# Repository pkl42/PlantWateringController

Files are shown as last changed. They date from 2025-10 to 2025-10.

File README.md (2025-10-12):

# PlantWateringController

An open-source IoT system for **automated plant watering and monitoring**, built around an **ESP32 controller**, **Tasmota ESP8266 sensors**, and a **Node-RED dashboard** with **InfluxDB** time-series storage.

---

## Features
- ESP32-based **Plant Controller** for moisture-driven watering control  
- ESP8266 Wi-Fi sensors (Tasmota) with **deep sleep** and MQTT telemetry  
- **Node-RED Dashboard 2.0** for live visualization and manual override  
- **InfluxDB 2.0** for time-series logging and analytics  
- Modular 3D-printed housings (Fusion 360) for pumps, sensors, and enclosures  
- Supports both **wired** and **wireless** capacitive moisture sensors

---

## System Overview

[ ESP8266 Sensor ] ─── MQTT ───┐
│
[ Node-RED ] ─── [ InfluxDB ]
│
[ ESP32 Controller ] <─────────┘

---

## Quick Start

### 1️⃣ Flash the ESP32 Controller
- Code in: `/firmware/esp32_controller`
- Built using **PlatformIO**
- Configure Wi-Fi and MQTT broker in `config.h`

### 2️⃣ Configure ESP8266 Sensor
- Flash **Tasmota**
- Apply rules from `/firmware/esp8266_sensor_tasmota/tasmota_rules.md`
- Set up **telemetry** every few minutes
- Example payload: `tele/plantSensor/STATE`

### 3️⃣ Import Node-RED Flow
- Import `/nodered/flows.json`
- Set MQTT and InfluxDB connection nodes
- Adjust dashboard layout if needed

### 4️⃣ InfluxDB Setup
- Create a bucket, retention policy, and token
- See `/influxdb/retention_policy_setup.md`

### 5️⃣ Optional Hardware Setup
- Print 3D housings from `/cad/`
- See `/docs/build_guide.md` and `/docs/wiring.md`

---

## Repository Structure
| Folder | Description |
|---|---|
| `firmware/` | ESP32 controller firmware + Tasmota sensor setup |
| `nodered/` | Dashboard flow and UI elements |
| `cad/` | Fusion 360 source, STL exports, and renders |
| `hardware/` | Wiring diagrams and bill of materials |
| `influxdb/` | Database configuration and example queries |
| `docs/` | Guides, build notes, and overviews |

---

## Recommended Tools
- [PlatformIO](https://platformio.org/)
- [Node-RED Dashboard 2.0](https://flows.nodered.org/)
- [InfluxDB 2.x](https://www.influxdata.com/)
- [Fusion 360](https://www.autodesk.com/products/fusion-360/)
- [Fritzing](https://fritzing.org/) (optional for wiring diagrams)

---

## License
This project is open-source.  
You can use or modify it under the **Apache 2.0 License** (see [LICENSE](LICENSE)).

---

## Author
Created by **Peter Ludwig**  
Designed for modular smart plant care and automation.

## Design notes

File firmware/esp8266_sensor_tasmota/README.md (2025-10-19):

# ESP8266 Tasmota Moisture Sensor Firmware

This folder contains the setup and configuration guide for using an ESP8266-based soil moisture sensor running **Tasmota** firmware within the Plant Watering Controller system.

## Overview

This setup turns a low-cost ESP8266 board (e.g. Wemos D1 Mini) into a self-contained soil moisture sensor.  
It reads the analog input (A0), publishes the value via MQTT, and can enter **deep sleep** to save power.

---

## Installation Guide

### 1. Download and Flash Tasmota

**Note 1:** For flashing the wiring between D0 and RST needs to be interupted.  
**Note 2:** Your browser does need to support Web Serial, use Google Chrome or Microsoft Edge.

1. Go to [https://tasmota.github.io/install/](https://tasmota.github.io/install/).
2. Connect your ESP8266 board via USB.
3. Select **Tasmota Sensors** from your browser.
4. Configure your Wi-Fi Access right now and click on "Visit Device"-Option.
or  
5. Connect to the Wi-Fi access point created by the ESP8266 (SSID `tasmota-XXXX`).
6. Enter your Wi-Fi credentials and reconnect to your network.

**Note 3:** After flashing the wiring between D0 and RST needs to be reconnected.  

Additional Information: [https://tasmota.github.io/docs/Getting-Started/#initial-configuration](https://tasmota.github.io/docs/Getting-Started/#initial-configuration)

---

### 2. Initial Setup

1. Access the Tasmota web interface (just the ip-address of the connected device, e.g. <http://192.168.0.186>).  
   You can get it e.g. from your router in the list of connected devices.  
   If you configured the Wi-Fi Access right during flashing process you can directly click on the  
   "Visit Device"-Option.
2. Go to **Configuration → Module → Module Type: Generic (18)**. Then click on Save to restart the device.
3. Go to **Configuration → Module and now set the Module Parameters like on the screenshot.

#### Template & Pin Configuration

| Setting | Description |
|---|---|
| Module Type | Generic (18) |
| A0 | Analog sensor input |
| Power1 | GPIO used to power the sensor (optional) |
| Others | Leave unconfigured |

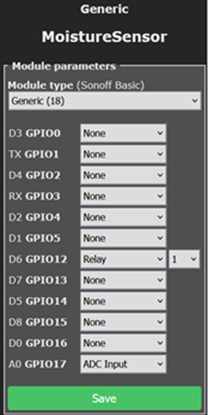
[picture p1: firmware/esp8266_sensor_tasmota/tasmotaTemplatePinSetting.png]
Generic Template Setting
  

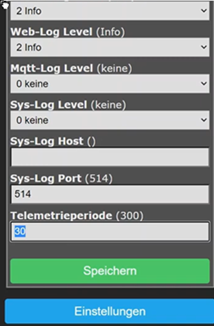
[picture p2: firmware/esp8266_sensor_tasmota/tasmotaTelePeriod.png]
TelePeriod Configuration
  

---

### 3. Configure MQTT

Set your MQTT broker connection in **Configuration → Configure MQTT**:

| Setting | Example |
|---|---|
| Host | `192.168.1.105` |
| Port | `1883` |
| Topic | `MS_%06X` |

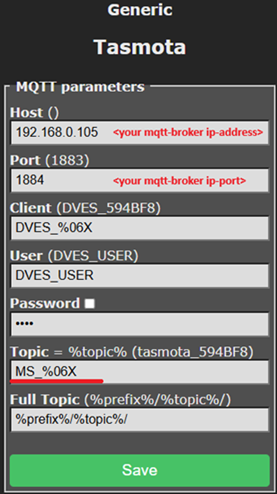
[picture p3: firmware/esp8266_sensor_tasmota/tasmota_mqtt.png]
MQTT Configuration


---

### 4. Load the Rules

Paste the rules from [`tasmota_rules.md`](./tasmota_rules.md) into the **Tasmota Console**, then enable them:

Enable rules:

~~~bash
Rule1 1

ruletimer1 3
~~~

The rule handle ADC reading, MQTT publishing, and optionally entering deep sleep mode.  
The <device_topic> is also used in the plant controller in Nodered, and as it should not be modified,  
mark the device with this <device_topic>.

---

### 5. MQTT Communication

The sensor periodically publishes its moisture readings via MQTT.  
You can manually set the deep sleep interval by publishing to:

~~~bash
cmnd/MS_594908/Mem3 0
~~~

| Value | Meaning |
|---|---|
| `0` | Stay awake (no sleep) |
| `>0` | Deep sleep time in seconds |

Example telemetric message: [`tele_format_example.json`](./tele_format_example.json)

~~~json
{
  "Time": "2025-10-06T15:29:58",
  "utctime": 1759760998,
  "adc": 268
}
~~~

---

Some mqtt commands i used during testing

~~~bash
mosquitto_pub -h 192.168.0.105 -t cmnd/MS_594908/mem3 -m <x>    # 0 No DeepSleep >0 DeepSleep in seconds

-r retained
-n delete retained message
mosquitto_pub -h 192.168.0.105 -t cmnd/MS_594908/mem3 -r -n 
~~~

---

## See Also

- [Node-RED integration](../../nodered/README.md)
- [InfluxDB example queries](../../influxdb/example_queries.md)
- [Hardware notes](../../hardware/README.md)

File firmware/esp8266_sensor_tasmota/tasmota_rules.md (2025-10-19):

# Tasmota Rules for Moisture Sensor

This rule control the ESP8266 moisture sensor behavior, MQTT reporting, and deep sleep cycle.  
The power for the sensor is controlled by output pin

---

## Rule1

~~~text
Rule1
ON System#Boot DO Backlog Power1 1; TelePeriod 30; Var3 2; DeepSleepTime 0 ENDON
  
ON Mqtt#Connected DO RuleTimer1 3 ENDON

ON Mem1#state= do backlog if ($Mem1 == "") Mem1 752 endon
ON Mem2#state= do backlog if ($Mem2 == "") Mem2 283 endon

ON Analog#A0 DO 
 Var1 %value%
 ENDON
 
ON Rules#Timer=1 DO 
 Backlog
 publish2 tele/%topic%/MOISTURE {"Time":"%timestamp%","utctime":%utctime%,"adc":%Var1%};
 Var3 = %Var3%-1;

 IF ((%Mem3%>0) && (%Var3%<1)) Backlog Publish stat/%topic%/debug Going_to_sleep; DeepSleepTime %Mem3% ENDIF;
 IF (%Mem3%==0 || %Var3%>0) Backlog Publish stat/%topic%/debug Restart_Timer1; RuleTimer1 10; DeepSleepTime %Mem3% ENDIF;

ENDON
~~~

**Explanation**

| Variable | Description |
| --- | --- |
| `Var1` | Stores latest ADC (moisture) value |
| `Var3` | Countdown until deep sleep |
| `Mem1`, `Mem2` | Optional calibration memory values, currently decomissioned  |
| `Mem3` | DeepSleepTime in seconds (set via MQTT) |
| `TelePeriod` | Telemetry interval |
| `Power1` | Turns sensor supply pin ON |
| `RuleTimer1` | Timer controlling when moisture data is sent |

**MQTT Command to Set Sleep Time**

cmnd/<device_topic>/Mem3 <seconds>

~~~text
cmnd/MS_594908/Mem3 600
~~~

→ Sleeps for 10 minutes after sending next telemetry packet.  
When device returns from Deepsleep, the DeepSleepTime is set to 0. Otherwise there would be no chance  
to switch off the deep sleep mode by mqtt message. Vice versa to fall in deep sleep again the
cmnd/<device_topic>/Mem3-topic should be retained message.

Debug Output (Example)

~~~text
stat/<device_topic>/debug Restart_Timer1
stat/<device_topic>/debug Going_to_sleep

stat/MS_594908/debug Restart_Timer1
stat/MS_594908/debug Going_to_sleep
~~~

These messages are useful for monitoring device behavior in Node-RED or the MQTT broker.

---

### **firmware/esp8266_sensor_tasmota/tele_format_example.json**

~~~json
{
  "Time": "2025-10-06T15:29:58",
  "utctime": 1759760998,
  "adc": 268
}
~~~

### Experiences and Issues

During developing the rule i tried to do the conversion into percentage value within the rule,  
but for some reason the calculated value delayed significant from raw value.

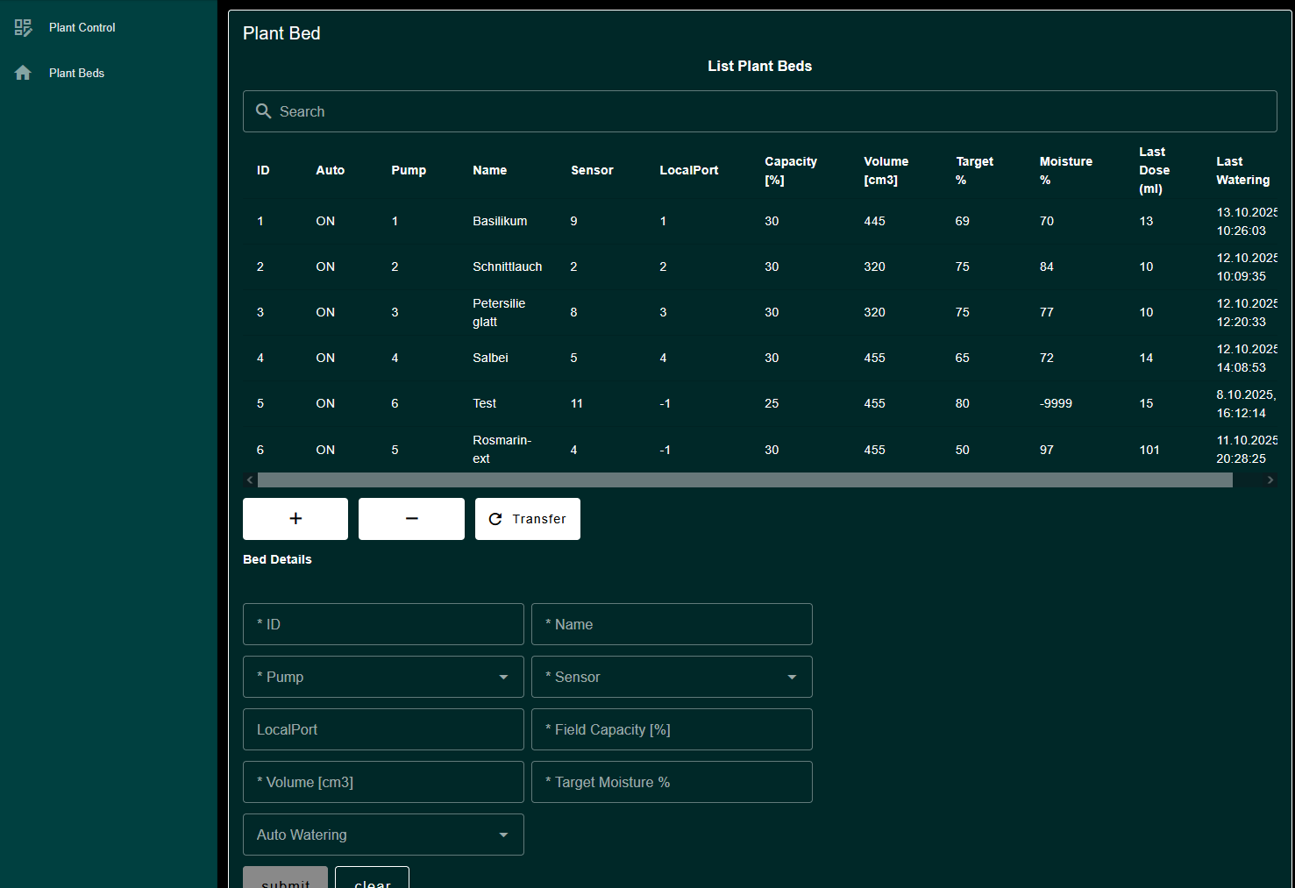
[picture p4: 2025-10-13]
nodered/dashboard_screenshots/PlantBeds.png

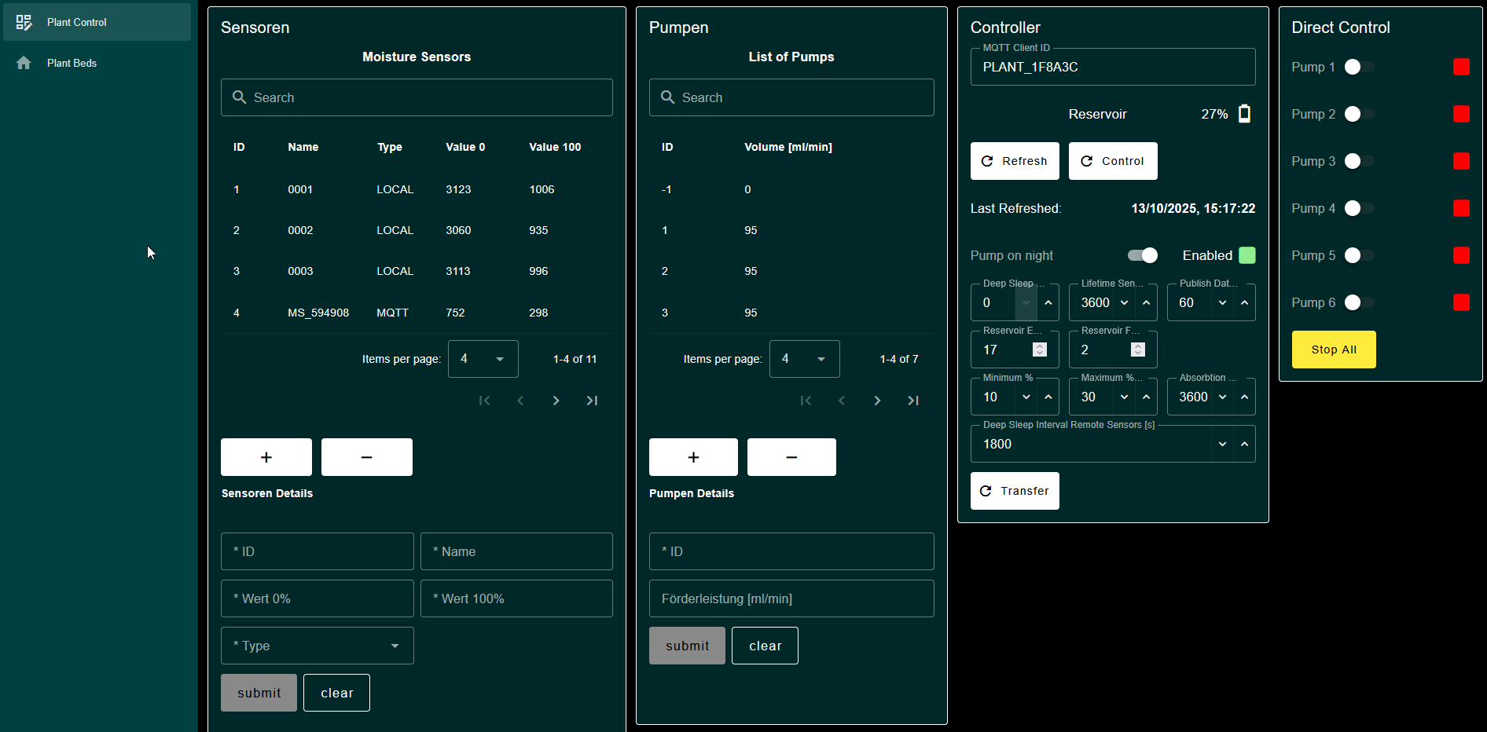
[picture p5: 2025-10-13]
nodered/dashboard_screenshots/PlantControl.png

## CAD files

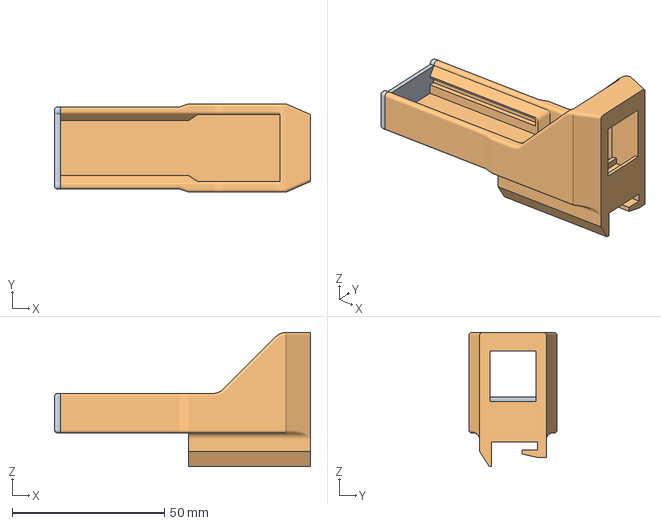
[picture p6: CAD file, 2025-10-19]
cad/clamps_tubes/SensorDistributorBox_V2.3mf
84.0 x 29.0 x 44.0 mm
Körper1 x 2

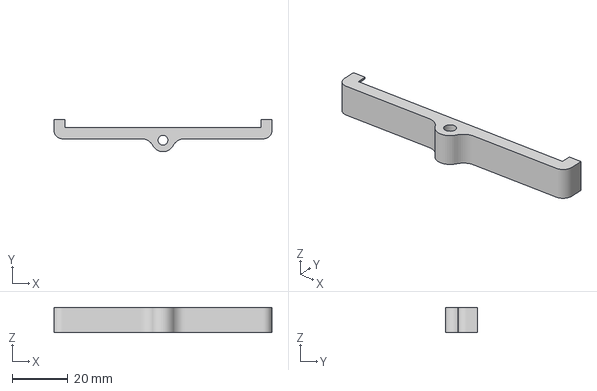
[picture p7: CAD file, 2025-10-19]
cad/main_box/MOSFET BoardHolder.3mf
78.0 x 11.6 x 9.00 mm

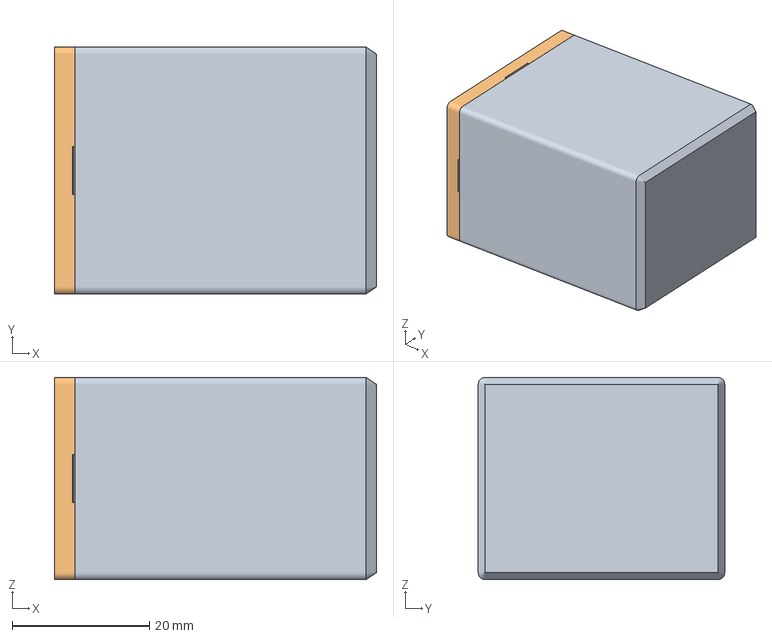
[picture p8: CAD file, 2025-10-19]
cad/sensor_unit/SensorHousing_450mAh_V1.8.3mf
47.0 x 36.0 x 29.5 mm
SensorHousing_450mAh
SensorHousing_450mAh_Base

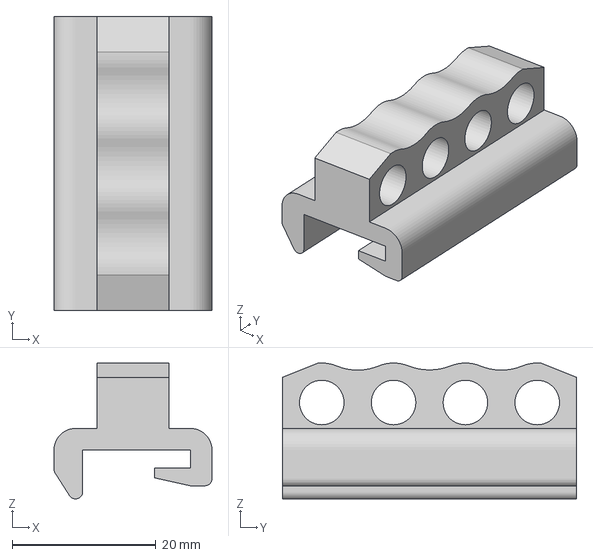
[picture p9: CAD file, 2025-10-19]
cad/clamps_tubes/ClampAdapter_Tubes_V2.3mf
22.0 x 41.0 x 18.9 mm

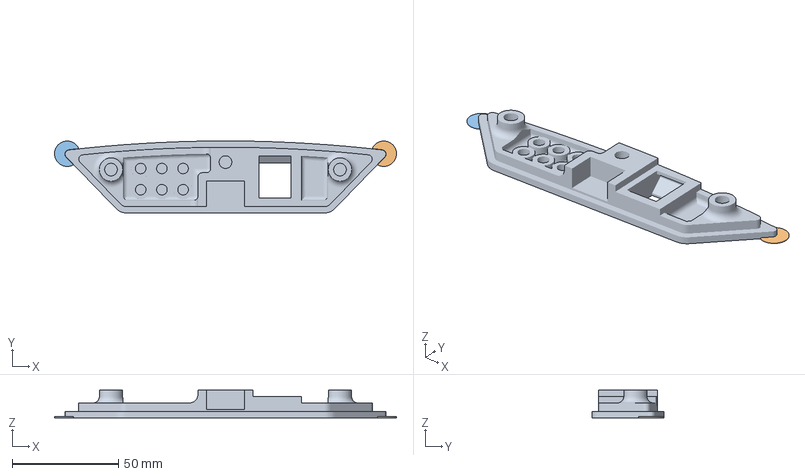
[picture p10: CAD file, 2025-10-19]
cad/main_box/GrabHandleAdapter_RJ45.3mf
161.3 x 34.0 x 13.0 mm
Körper1
Körper2
Körper3

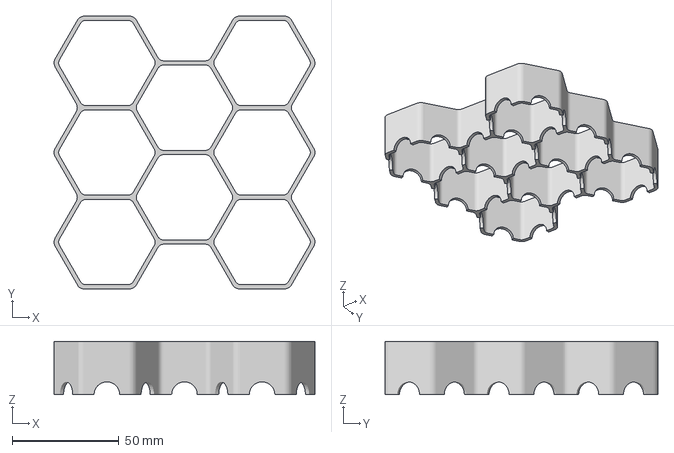
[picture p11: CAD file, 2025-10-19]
cad/miscellaneous/PlantSaucer.3mf
122.3 x 128.0 x 25.0 mm

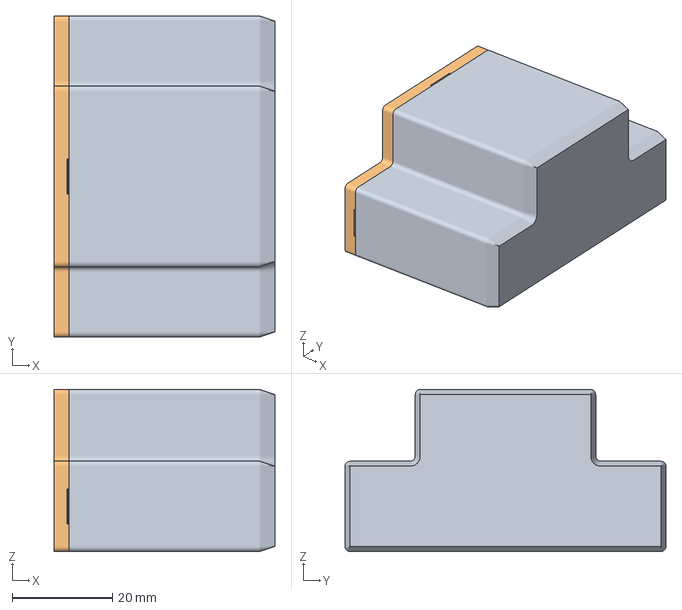
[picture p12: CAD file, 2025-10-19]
cad/sensor_unit/SensorHousing_2000mAh_V2.6.3mf
44.0 x 64.0 x 32.3 mm
SensorHousing_2000mAh
SensorHousing_2000mAh_Base

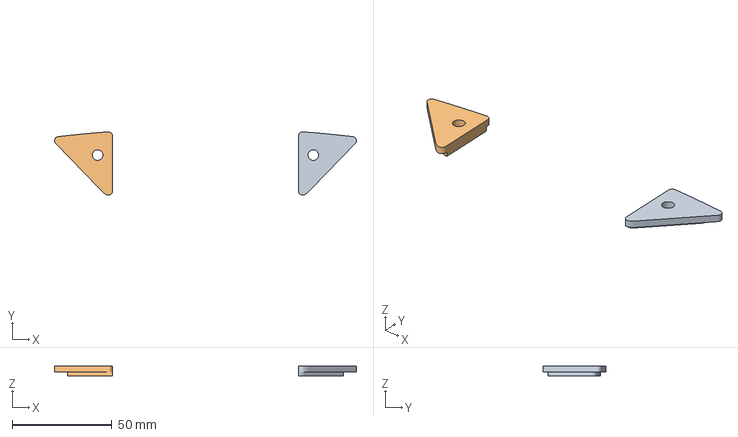
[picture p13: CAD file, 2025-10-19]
cad/main_box/Counterparts.3mf
151.3 x 31.7 x 5.00 mm
Körper1 x 2

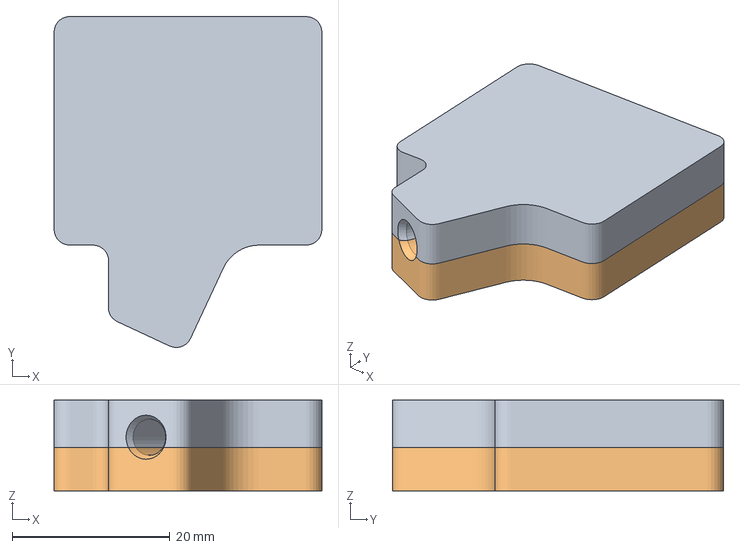
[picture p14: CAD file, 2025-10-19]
cad/sensor_unit/SensorHousingDirect.3mf
34.0 x 42.0 x 11.5 mm
SensorHousingNative1
SensorHousingNative2

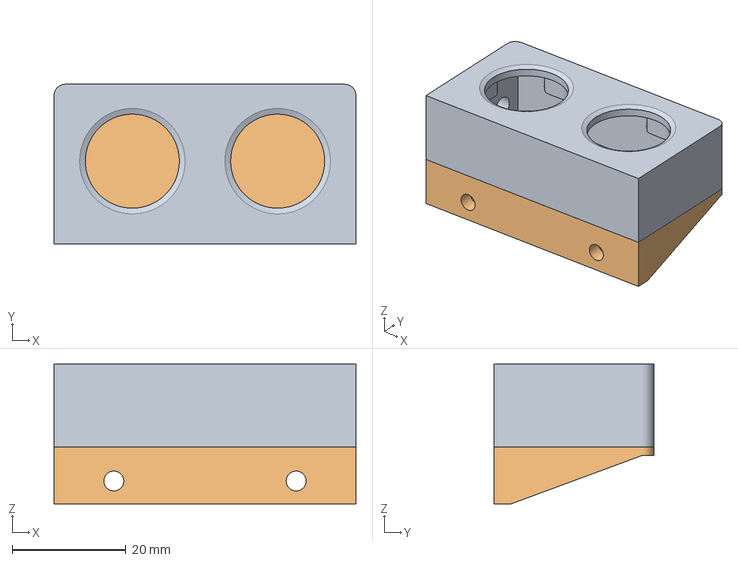
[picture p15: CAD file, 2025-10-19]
cad/main_box/UltrasonicSensor_HC-SR04 _V2.3mf
53.0 x 28.0 x 24.5 mm
Körper1 x 2

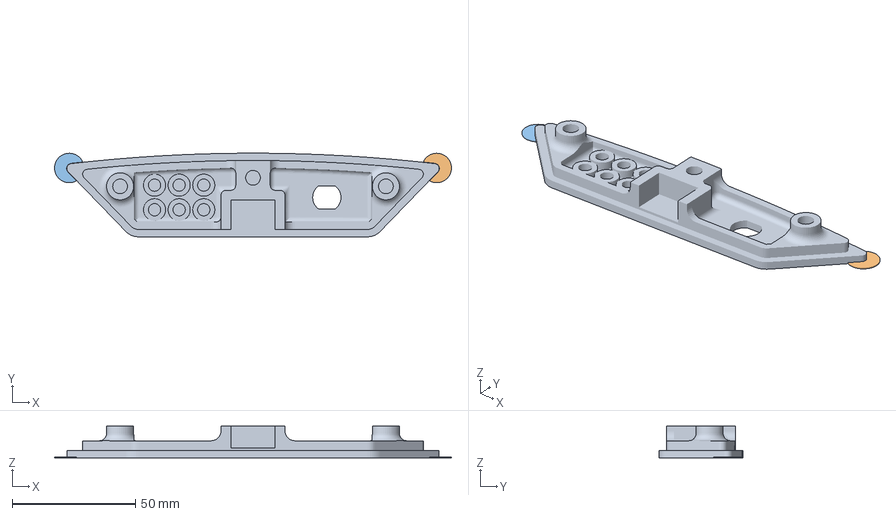
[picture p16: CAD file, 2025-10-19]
cad/main_box/GrabHandleAdapter_USB.3mf
161.3 x 34.0 x 13.0 mm
Körper1
Körper2
Körper3

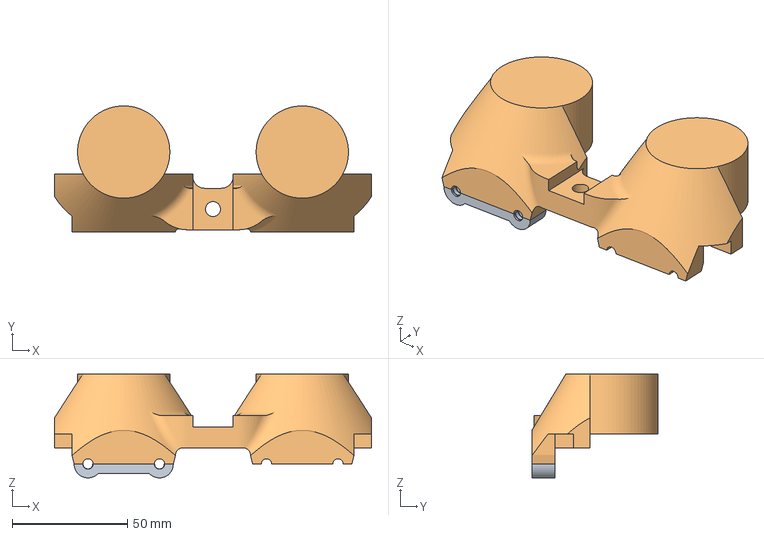
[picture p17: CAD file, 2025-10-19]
cad/main_box/PumpHolder_V4.3mf
137.4 x 54.7 x 45.0 mm
Körper2 x 2

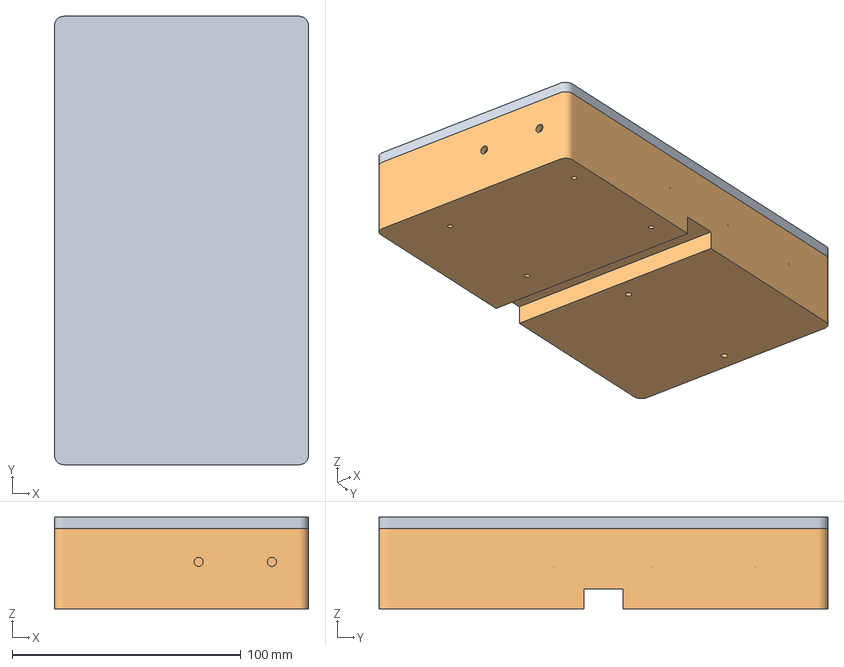
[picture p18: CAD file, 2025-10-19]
cad/main_box/ControlCabinet_V1.3mf
111.0 x 196.0 x 40.0 mm
Körper1 x 2

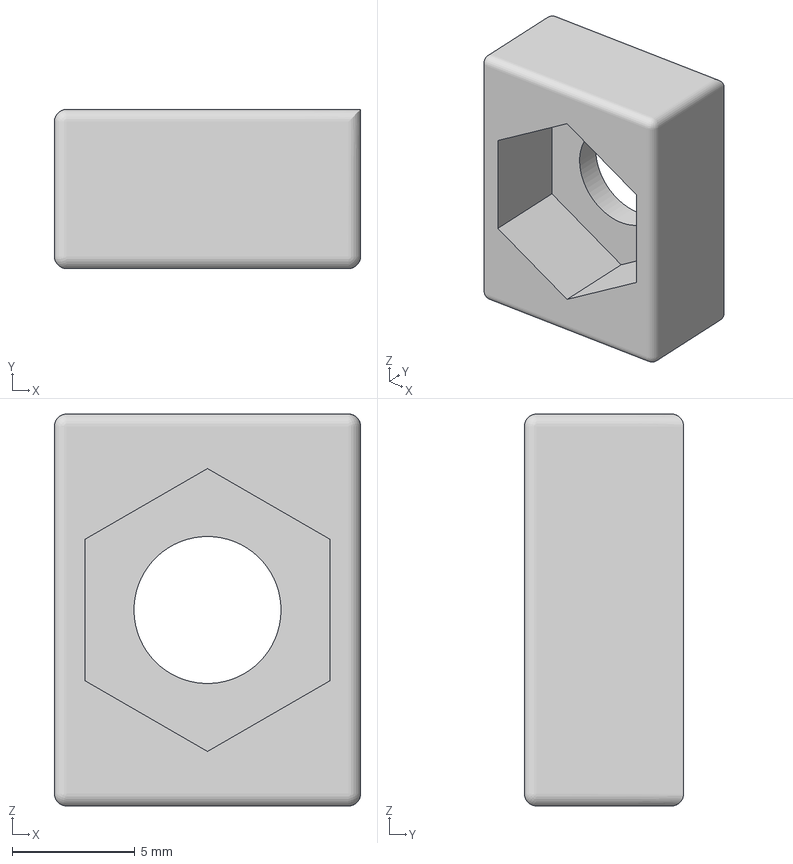
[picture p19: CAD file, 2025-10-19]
cad/miscellaneous/T-Nut_M6_Nut.3mf
12.5 x 6.50 x 16.0 mm

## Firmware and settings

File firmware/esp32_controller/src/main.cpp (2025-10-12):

/*
 * SPDX-FileCopyrightText: 2025 Peter Ludwig
 *
 * SPDX-License-Identifier: Apache-2.0
 */

#include "PlantController.h"
#include <configFile.h>
#include <DualWifiMode.h>
#include "WebServerBase.h"
#include "OTAHandler.h"

JsonDocument config_doc;
MyAppConfig config("/config.cfg");
WebConfigServer configServer(80);

TimeZone tz("pool.ntp.org", "CET-1CEST,M3.5.0,M10.5.0/3");
PlantController controller(tz);

// Manual IP Configuration for Soft AP
IPAddress AP_LOCAL_IP(192, 168, 5, 10);
IPAddress AP_GATEWAY_IP(192, 168, 5, 254);
// Url for access: http://192.168.5.10/
// Define Pin to indicate start option
const uint8_t AP_PIN = 23; // do not use GPIO11!!!-crashes

void setup()
{
  WiFiModeStatus wifi_status;
  Serial.begin(115200);
  delay(200);
  Serial.println("=== ESP32 Plant Watering Controller ===");

  // config.remove();
  config_doc = config.read_config();

  initDualWiFiConfig(AP_PIN,
                     config_doc["ap_ssid"],
                     config_doc["ap_password"],
                     config_doc["ln_ssid"],
                     config_doc["ln_password"],
                     AP_LOCAL_IP,
                     AP_GATEWAY_IP);

  wifi_status = startDualWiFi();

  if (wifi_status == WiFiModeStatus::AP)
  {
    configServer.setDefaults(config_doc);
    configServer.onConfigSaved([&](const JsonDocument &doc)
                               { config.write_config(&doc); });
    Serial.println("start");
    configServer.start();
  }

  // Init OTA (you can also pass hostname and password if desired)
  setupOTA("esp32-ota", nullptr);

  // Init Plant Controller

  controller.init(config_doc["mqtt_broker_ip"],
                  static_cast<uint16_t>(config_doc["mqtt_broker_port"].as<int>()));
}

void loop()
{
  if (!otaInProgress)
  { // only run normal tasks if OTA is not happening
    // In deep sleep mode, run() will sleep at the end
    // In continuous mode, run() will return immediately and be called again
    if (controller.connectToMQTTBroker())
    {
      controller.subscribeCmndTopics();
      controller.run();
    }
  }

  handleOTA(); // must be called regularly
}

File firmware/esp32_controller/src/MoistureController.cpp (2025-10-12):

/*
 * SPDX-FileCopyrightText: 2025 Peter Ludwig
 *
 * SPDX-License-Identifier: Apache-2.0
 */

#include "MoistureController.h"
#include <ArduinoJson.h>

#include "esp_log.h"

IMoistureSensor::IMoistureSensor(TimeZone &timeZone, const String &sensorName)
    : tz(timeZone), sensorName(sensorName)
{
}

void IMoistureSensor::setCalibration(int dry, int wet)
{
    if (dry != VALUE_NOT_SET)
    {
        rawDry = dry;
    }
    if (wet != VALUE_NOT_SET)
    {
        rawWet = wet;
    }
}

void IMoistureSensor::setRaw(int rawValue, unsigned long utcTime)
{
    lastReadRaw = rawValue;

    if (utcTime > 0)
    {
        // Use provided UTC/Epoch timestamp
        lastUpdateRaw = utcTime;
        lastUpdateRawUsingEpoch = true;
        // ESP_LOGI("", "setRaw utcTime %lu, %lu, %i, %i", utcTime, lastUpdateRaw, lastReadRaw, lastUpdateRawUsingEpoch);
    }
    else
    {
        // Fallback to system time or millis
        lastUpdateRaw = tz.getNow(lastUpdateRawUsingEpoch);
        // ESP_LOGI("", "setRaw Fallback %lu, %i, %i", lastUpdateRaw, lastReadRaw, lastUpdateRawUsingEpoch);
    }
}

void IMoistureSensor::setPercent(float percentValue, unsigned long utcTime)
{
    lastReadPer = percentValue;

    if (utcTime > 0)
    {
        // Use provided UTC timestamp
        lastUpdatePer = (unsigned long)utcTime * 1000UL;
        lastUpdatePerUsingEpoch = true;
    }
    else
    {
        // Fallback to system time or millis
        lastUpdatePer = tz.getNow(lastUpdatePerUsingEpoch);
    }
    // ESP_LOGI("", "setPercent %u, %i", lastUpdateRaw, lastReadRaw);
}

bool IMoistureSensor::isDataValid(unsigned long lastUpdate, bool dateInUtc)
{
    unsigned long nowMs = tz.getNow(lastCheckUtc);
    return (nowMs - lastUpdate) <= maxLifetimeMs;
}

void IMoistureSensor::setLifetime(unsigned int lifetimeSec)
{
    maxLifetimeMs = lifetimeSec * 1000UL;
    ESP_LOGI(sensorName, "Lifetime updated to %u seconds", lifetimeSec);
}

unsigned int IMoistureSensor::getLifeTime()
{
    return (unsigned int)(maxLifetimeMs / 1000UL);
}

//
// private functions
//

//
// MoistureSensorLocal
//
MoistureSensorLocal::MoistureSensorLocal(TimeZone &timeZone, const String &sensorName, int pin, int dry, int wet)
    : IMoistureSensor(timeZone, sensorName)
{
    IMoistureSensor::connType = ConnectionType::LOCAL;
    sensorPin = pin;
    setCalibration(dry, wet);
}

void MoistureSensorLocal::init()
{
    if (sensorPin > 0)
    {
        analogSetPinAttenuation(sensorPin, ADC_11db);
        analogReadResolution(12);
        // Enable internal pull-up to bias floating pin
        pinMode(sensorPin, INPUT_PULLUP);
        analogRead(sensorPin); // warm-up read
    }
}

void MoistureSensorLocal::setPin(int pin)
{
    if (pin == sensorPin)
    {
        return;
    }

    sensorPin = pin;
    init();
}

MoistureData MoistureSensorLocal::readPercent()
{
    MoistureData result{};
    result.percent = INVALID_FLOAT;
    result.timestamp = 0;

    int raw = readRaw();
    if (raw == INVALID_INT)
    {
        return result;
    }
    result.timestamp = getRawTimestamp();

    if (rawWet == rawDry)
    {
        result.percent = 100.0f; // fail-safe: assume fully wet
        return result;
    }

    float pct = ((float)(rawDry - raw) * 100.0f) / (float)(rawDry - rawWet);
    pct = constrain(pct, 0.0f, 100.0f);

    result.percent = pct;

    return result;
}

int MoistureSensorLocal::readRaw()
{
    const int samples = 8;
    long acc = 0;
    for (int i = 0; i < samples; i++)
    {
        acc += analogRead(sensorPin);
        delay(2);
    }
    lastReadRaw = (acc / samples);
    // --- Detect invalid reading ---
    // Your "dry" baseline is around 3100–3200.
    // Floating w/ pull-up will be closer to 4095 (max at 12-bit).
    int helpInt = lastReadRaw;
    if ((lastReadRaw > 3500) || (lastReadRaw < 800))
    {
        // Mark as invalid (you can choose 0, -1, or a special flag)
        lastReadRaw = INVALID_INT;
    }
    // ESP_LOGI("", "%s lastReadRaw %i => %i", (this->getSensorName()).c_str(), helpInt, lastReadRaw);
    setRaw(lastReadRaw);
    return lastReadRaw;
}

//
// ----- MoistureSensorMQTT Class -----
//

const char *TOPIC_MOISTURE = "MOISTURE";
const char *TOPIC_SENSOR_TASMOTA = "SENSOR";

MoistureSensorMQTT::MoistureSensorMQTT(TimeZone &timeZone, const String &sensorName,
                                       int dry,
                                       int wet,
                                       unsigned long lifeTimeSec)
    : IMoistureSensor(timeZone, sensorName)
{
    IMoistureSensor::connType = ConnectionType::MQTT;
    maxLifetimeMs = (lifeTimeSec * 1000UL);
    setCalibration(dry, wet);
}

void MoistureSensorMQTT::init()
{
    // the mqttCallback is called from global mqttCallback function
    // mqttClient.setCallback([this](char *topic, byte *payload, unsigned int length)
    //                        { this->mqttCallback(topic, payload, length); });

    // mqttClient.subscribe(mqttTopicBuilder(sensorID, CLASS_STATE, TOPIC_MOISTURE, -1, "#").c_str(), 1);
}

int MoistureSensorMQTT::readRaw()
{
    if (!isDataValid(lastUpdateRaw, lastUpdateRawUsingEpoch))
    {
        // ESP_LOGW("MoistureMQTT", "Data expired for %s", sensorName.c_str());
        lastReadRaw = INVALID_INT;
    }
    return lastReadRaw;
}
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

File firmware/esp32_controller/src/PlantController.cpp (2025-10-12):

/*
 * SPDX-FileCopyrightText: 2025 Peter Ludwig
 *
 * SPDX-License-Identifier: Apache-2.0
 */

#include <Arduino.h>
#include <ArduinoJson.h>
#include "PlantController.h"

#include <DualWifiMode.h>
#include <esp32-hal-adc.h>

unsigned long PlantController::sleepIntervalSeconds = 0UL; // 1800UL;

PlantController::PlantController(TimeZone &timezone)
    : tz(timezone),
      mqttClient(espClient),
      pumps(pumpPins),
      moistureController(moisturePins, timezone),
      reservoir(RESERVOIR_TRIG_PIN, RESERVOIR_ECHO_PIN, RESERVOIR_POWER_PIN),
      plantControllerConfig("/plantConfig.cfg"),
      mqttDispatcher(mqttClient)
{
}

void PlantController::init(const char *mqtt_broker, uint16_t mqtt_port)
{
    ESP_LOGI(TAG, "init Broker: %s : %u", mqtt_broker, mqtt_port);
    mqttClient.setServer(mqtt_broker, mqtt_port);
    mqttClient.setCallback([this](char *topic, byte *payload, unsigned int length)
                           { this->mqttDispatcher.mqttCallback(topic, payload, length); });

    mqttClient.setBufferSize(512);

    String mqttClientID = buildClientID(String(MQTT_CLIENT_ID_PREFIX), getDeviceID());
    mqttDispatcher.init(mqttClientID);

    pumps.init(mqttClient, mqttClientID);

    mqttDispatcher.registerHandler(
        mqttTopicBuilder(mqttClientID, CLASS_CMD, TOPIC_PUMP, -1, "#"),
        [this](const std::vector<String> &topic, const String &payload)
        {
            this->pumps.processMQTTMessage(topic, payload);
        });

    //

    moistureController.init(mqttClient, mqttClientID);

    mqttDispatcher.registerHandler(
        mqttTopicBuilder(mqttClientID, CLASS_CMD, TOPIC_MOISTURE, -1, "#"),
        [this](const std::vector<String> &topic, const String &payload)
        {
            this->moistureController.processMQTTMessage(topic, payload);
            // this->pumps->processMQTTMessage(topic, payload); // if pumps is a pointer
        });
    // when working with mqtt moisture sensors also the moistureController will handle these topics
    mqttDispatcher.registerHandler(
        mqttTopicBuilder("+", CLASS_TELE, TOPIC_MOISTURE, -1, "#"),
        [this](const std::vector<String> &topic, const String &payload)
        {
            this->moistureController.processMQTTMessage(topic, payload);
        });

    // read plant configuration from file
    // plantControllerConfig.remove();
    plant_config_doc = plantControllerConfig.read_config();
    JsonArray plant_arr = plant_config_doc["plants"];
    if (plant_arr.isNull() || plant_arr.size() != NUM_PLANTS)
    {
        ESP_LOGW(TAG, "plant_config_doc: Config invalid or missing, resetting to defaults");
        plantControllerConfig.remove();                         // delete corrupt file
        plant_config_doc = plantControllerConfig.read_config(); // re-create defaults
        plant_arr = plant_config_doc["plants"];
    }

    loadSetupFromConfig(plant_config_doc);
    // initialize used sensors
    for (uint8_t plantIdx = 0; plantIdx < NUM_PLANTS; ++plantIdx)
    {
        // Measure moisture
        ESP_LOGI("initSensor", "plantIdx %i, sensorID %i, sensorPort %i", plantIdx, plants[plantIdx].config.sensorID, plants[plantIdx].config.sensorPort);
        moistureController.initSensor(plants[plantIdx].config.sensorID, plants[plantIdx].config.sensorPort);
    }

    mqttDispatcher.registerHandler(
        mqttTopicBuilder(mqttClientID, CLASS_CMD, TOPIC_PLANT, -1, "#"),
        [this](const std::vector<String> &topic, const String &payload)
        {
            processMQTTPlantMessage(topic, payload);
        });

    // read and assign controller configuration

    reservoir.init(plant_config_doc["distEmptyCM"], plant_config_doc["distFullCM"]);

    control_mode = plant_config_doc["controlMode"]; // 20250912 deactivated
    enablePumpOnNightHours = plant_config_doc["enablePumpOnNightHours"];

    sleepIntervalSeconds = plant_config_doc["sleepIntervalSeconds"];
    publishIntervalSeconds = plant_config_doc["publishIntervalSeconds"];

    minWateringPCT = plant_config_doc["minWateringPCT"];
    maxWateringPCT = plant_config_doc["maxWateringPCT"];
    absorptionWaitSec = plant_config_doc["absorptionWaitSec"];

    sleeping_state = 0;
    bool pubStatus = mqttClient.publish(mqttTopicBuilder(mqttClientID, CLASS_STATE, TOPIC_SLEEPING_STATE).c_str(), String(sleeping_state).c_str());

    mqttDispatcher.registerHandler(
        mqttTopicBuilder(mqttClientID, CLASS_CMD, TOPIC_CONTROLLER, -1, "#"),
        [this](const std::vector<String> &topic, const String &payload)
        {
            processMQTTControllerMessage(topic, payload);
        });

    mqttDispatcher.registerHandler(
        mqttTopicBuilder(mqttClientID, CLASS_CMD, TOPIC_RESERVOIR, -1, "#"),
        [this](const std::vector<String> &topic, const String &payload)
        {
            processMQTTControllerMessage(topic, payload);
        });

    tz.maybeResync(24); // only sync if >24h since last s
}
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

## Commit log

2025-10-12 Imported ESP32 firmware into firmware/esp32_controller
2025-10-13 new file: nodered/dashboard_screenshots/PlantBeds.png new file: nodered/dashboard_screenshots/PlantControl.png new file: nodered/flows.json
2025-10-19 initial 3mf added
    [ClampAdapter_Tubes_V2.3mf, ControlCabinet_V1.3mf, Counterparts.3mf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]
2025-10-19 readme sensor created
